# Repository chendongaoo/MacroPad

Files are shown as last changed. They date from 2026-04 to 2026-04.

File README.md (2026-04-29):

# MacroPad
A 6 key and 1 rotary encoder macropad designed so I can learn pcbs.

This was my first time ever doing a hardware project involving PCBs so I would say this was a really educational and fun experience!

# CAD Model
The case of the macropad was built through AutoDesk Inventor




# PCB
I used KiCAD for the pcb design and also the schematics.

- Schematic
- Schematic Picture
- PCB Design
- PCB Picture

# Firmware
QMK Firmware was used in order to make the firmware of the macropad. I was able to let it have my 6 keys type different letters out and also have the rotary encoder be for volume.

# BOM (Bill of Materials)
|Quantity|Item|Link|
|---|---|---|
|1|Seeed XIAO RP2040|https://www.seeedstudio.com/XIAO-RP2040-v1-0-p-5026.html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|
|1|EC11 Rotary Encoder|https://keeb.io/products/rotary-encoder-ec11?srsltid=AfmBOopjsudrm_2NT5rApQGzpvWgGaP1affFDQzp-gO6didcxRWisLA-|
|4|M3x16mm Screws|https://www.homedepot.com/p/Hillman-M3-0-5-x-16-mm-Internal-Hex-Button-Head-Cap-Screws-16-Pack-44458/204801177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|
|6|MX-Style Switches|https://www.gateron.co/collections/mx-switches/products/gateron-switch-set|
|6|White Blank DSA Keycaps|https://www.adafruit.com/product/4998?srsltid=AfmBOoqWXq0PUuXsWHtaNkMeOQ-MZJd006PQ38bVfjTifiNstVszIAVgm1U|
|PCB Estimated Price|$2.10|

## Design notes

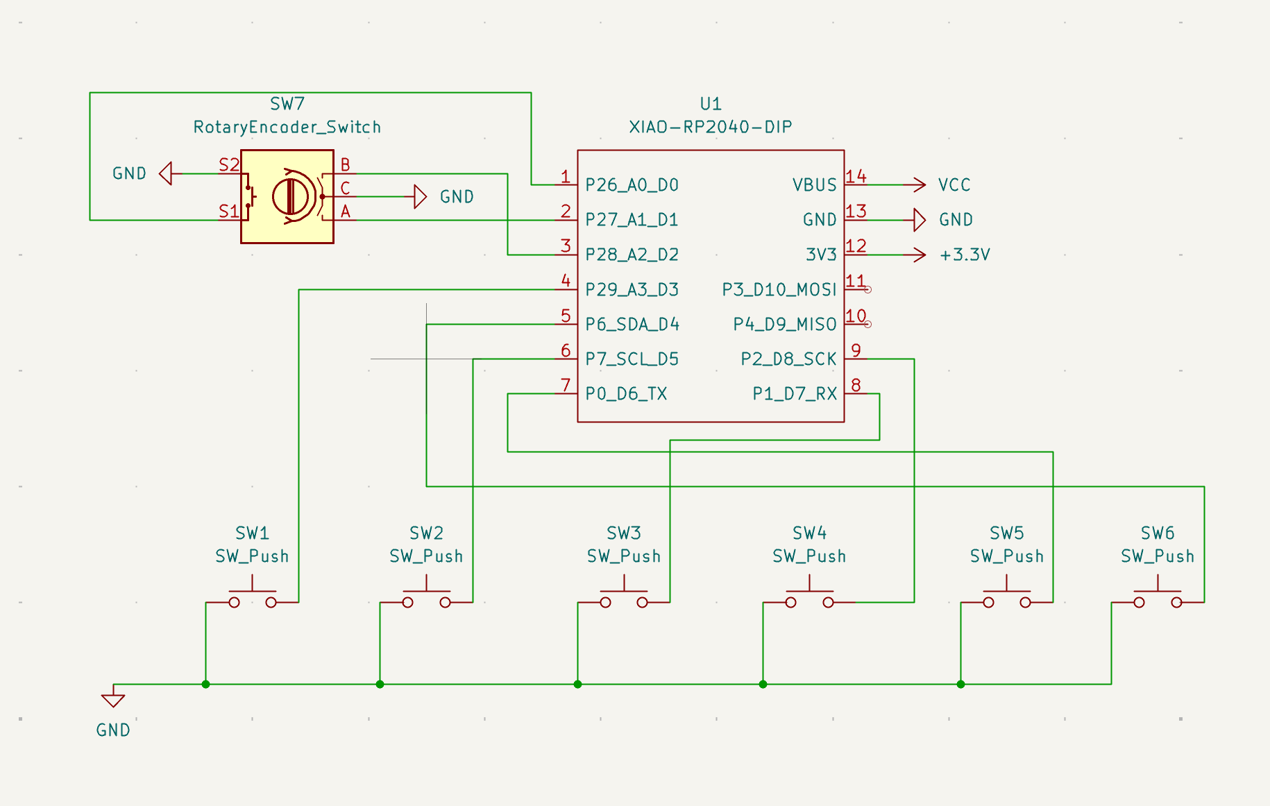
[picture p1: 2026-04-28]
PCB/Schematic Picture.png

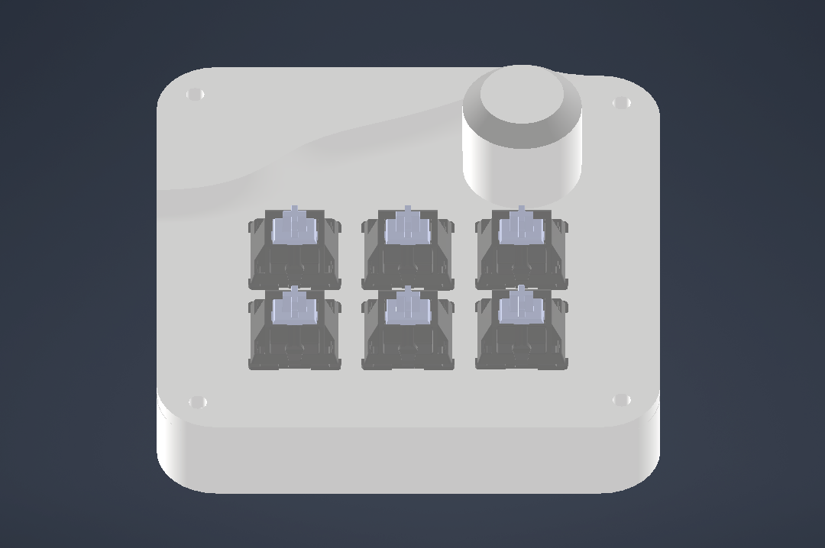
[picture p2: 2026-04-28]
CAD/Pic2.png

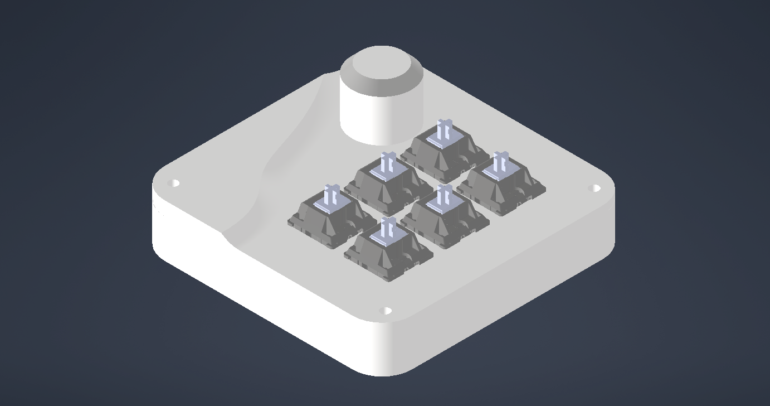
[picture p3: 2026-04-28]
CAD/Pic.png

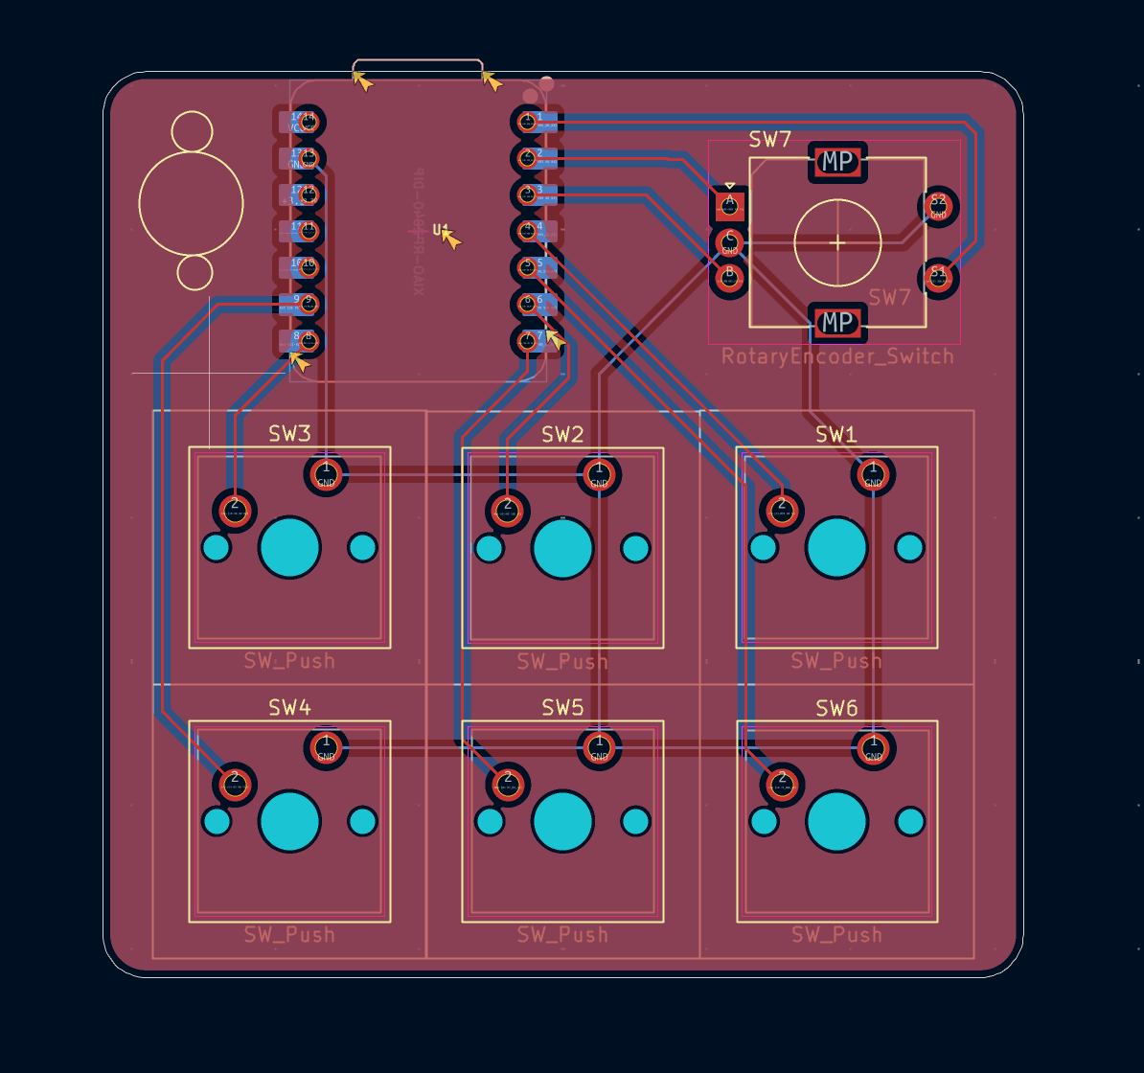
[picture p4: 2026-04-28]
PCB/PCB Picture.png

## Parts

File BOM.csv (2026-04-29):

Quantity | Item | Link
1 | Seeed XIAO RP2040 | https://www.seeedstudio.com/XIAO-RP2040-v1-0-p-5026.html
1 | EC11 Rotary Encoder | https://keeb.io/products/rotary-encoder-ec11
4 | M3x16mm Screws | https://www.homedepot.com/p/Hillman-M3-0-5-x-16-mm-Internal-Hex-Button-Head-Cap-Screws-16-Pack-44458/204801177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
6 | MX-Style Switches | https://www.gateron.co/collections/mx-switches/products/gateron-switch-set
6 | White Blank DSA Keycaps | https://www.adafruit.com/product/4998
PCB Estimated Price | $2.10

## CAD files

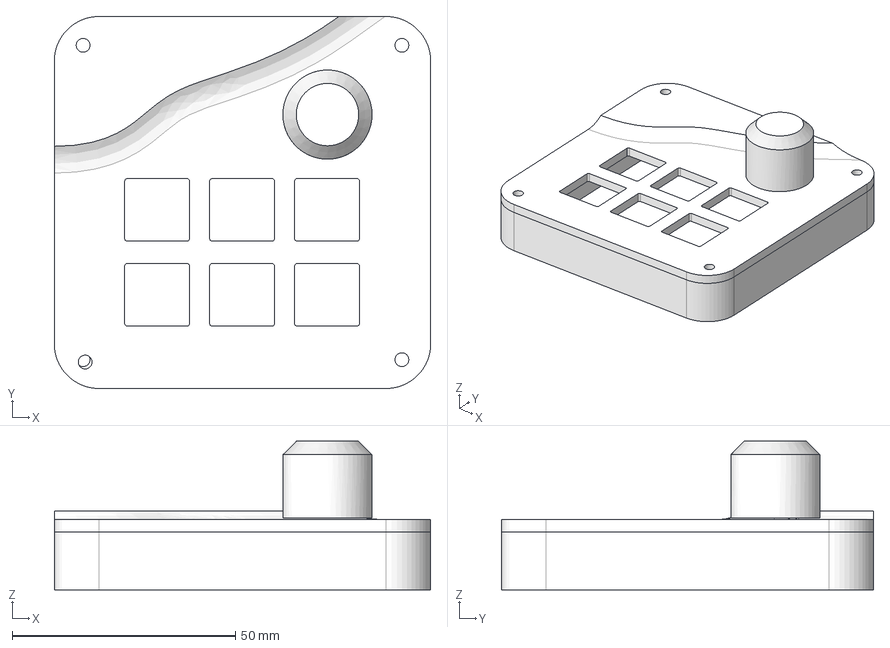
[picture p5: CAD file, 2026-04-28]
CAD/Assembly Files/MacroPadCase.stp
84.4 x 83.4 x 33.3 mm
Base
Cover
Knob

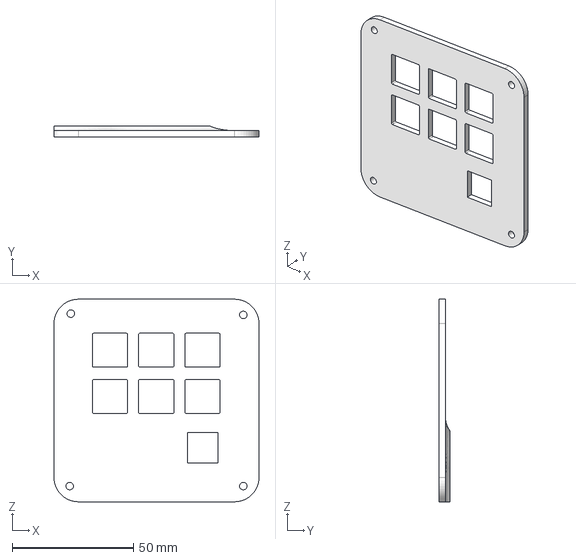
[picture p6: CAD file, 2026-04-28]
CAD/Part Files/Cover.stp
84.4 x 4.70 x 83.4 mm

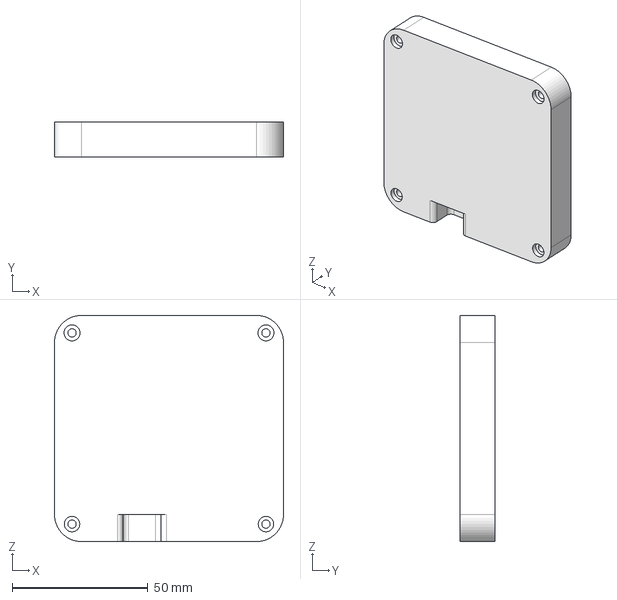
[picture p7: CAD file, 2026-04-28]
Production/Base.stp
84.4 x 13.0 x 83.4 mm

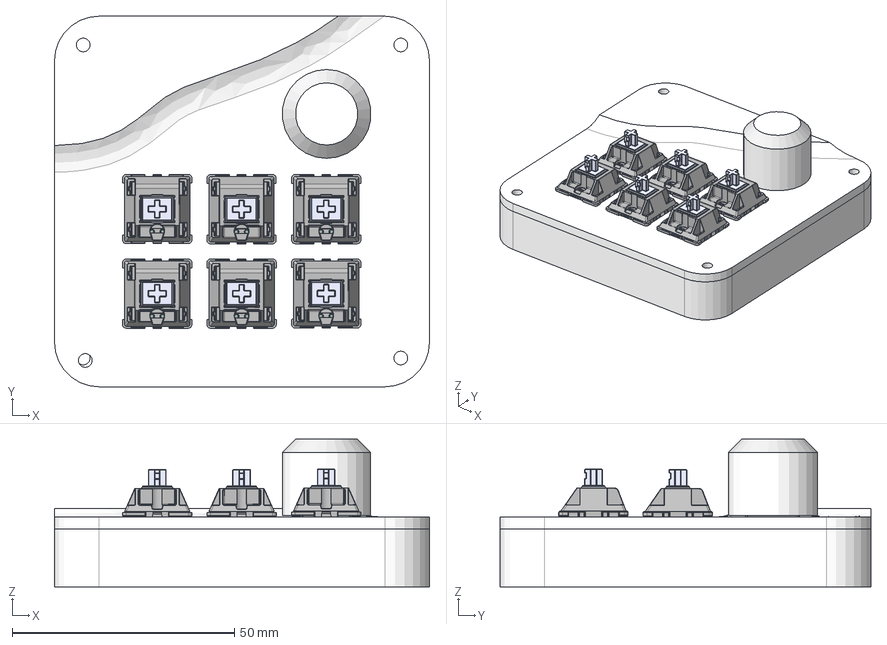
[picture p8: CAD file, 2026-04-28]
CAD/Assembly Files/MacroPadCase-PCB.stp
84.4 x 83.4 x 33.3 mm
���___Ĭ��__��_ x 6
MX�� ���� �ײ� �̡�2 __Ĭ��_��2____��_ x 6
MX �� ������_��_ __��1 x 6
MX �� ���娢��_���顧_ _ x 6
���___Ĭ��__��_ _1 x 6
Rotaryencoder
MacroPad_silkscreen
MacroPad_silkscreen_1
MacroPad_soldermask
MacroPad_soldermask_1
MacroPad_PCB
Base
Cover
Knob

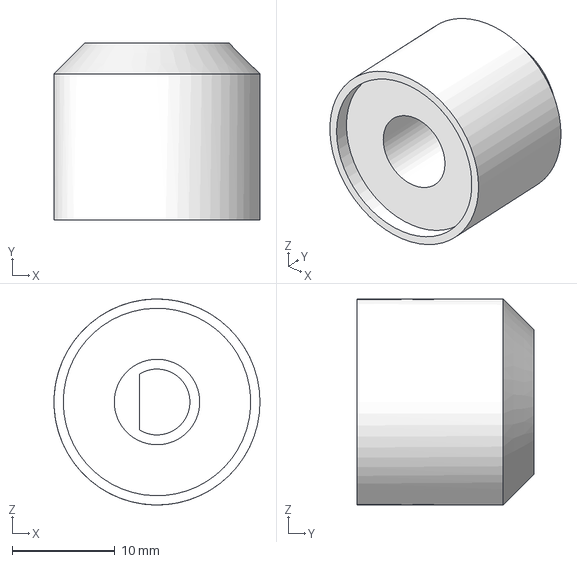
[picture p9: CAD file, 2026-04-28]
Production/Knob.stp
20.0 x 17.2 x 20.0 mm

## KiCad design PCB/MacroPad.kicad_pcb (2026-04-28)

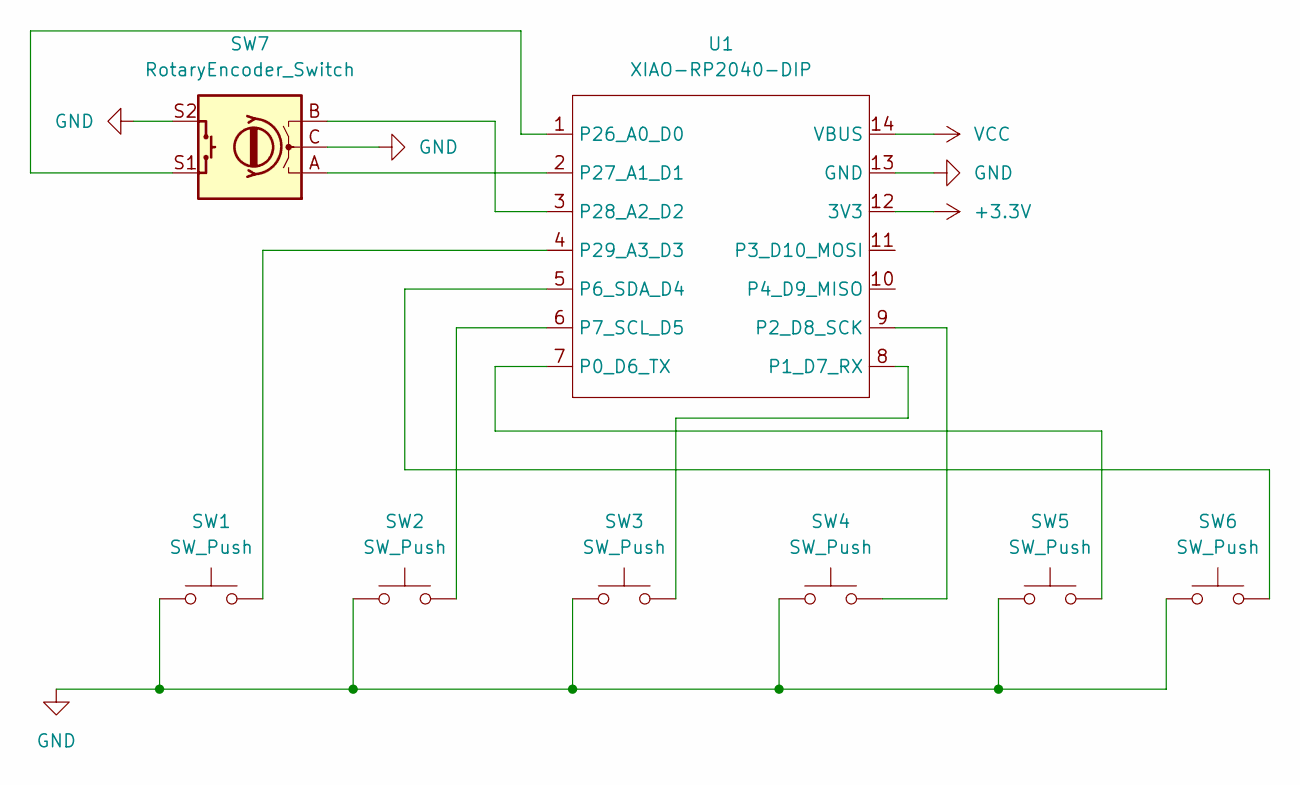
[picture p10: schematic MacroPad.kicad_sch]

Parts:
SW1, SW2, SW3, SW4, SW5, SW6: SW_Push; SW_Cherry_MX_1.00u_PCB
SW7: RotaryEncoder_Switch; RotaryEncoder_Alps_EC11E-Switch_Vertical_H20mm
U1: XIAO-RP2040-DIP

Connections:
+3.3V: U1.12 (3V3)
GND: SW1.1, SW2.1, SW3.1, SW4.1, SW5.1, SW6.1, SW7.C, SW7.S2, U1.13 (GND)
unnamed: SW5.2, U1.7 (P0_D6_TX)
unnamed: SW3.2, U1.8 (P1_D7_RX)
unnamed: SW4.2, U1.9 (P2_D8_SCK)
unnamed: SW6.2, U1.5 (P6_SDA_D4)
unnamed: SW2.2, U1.6 (P7_SCL_D5)
unnamed: SW7.S1, U1.1 (P26_A0_D0)
unnamed: SW7.A, U1.2 (P27_A1_D1)
unnamed: SW7.B, U1.3 (P28_A2_D2)
unnamed: SW1.2, U1.4 (P29_A3_D3)
VCC: U1.14 (VBUS)

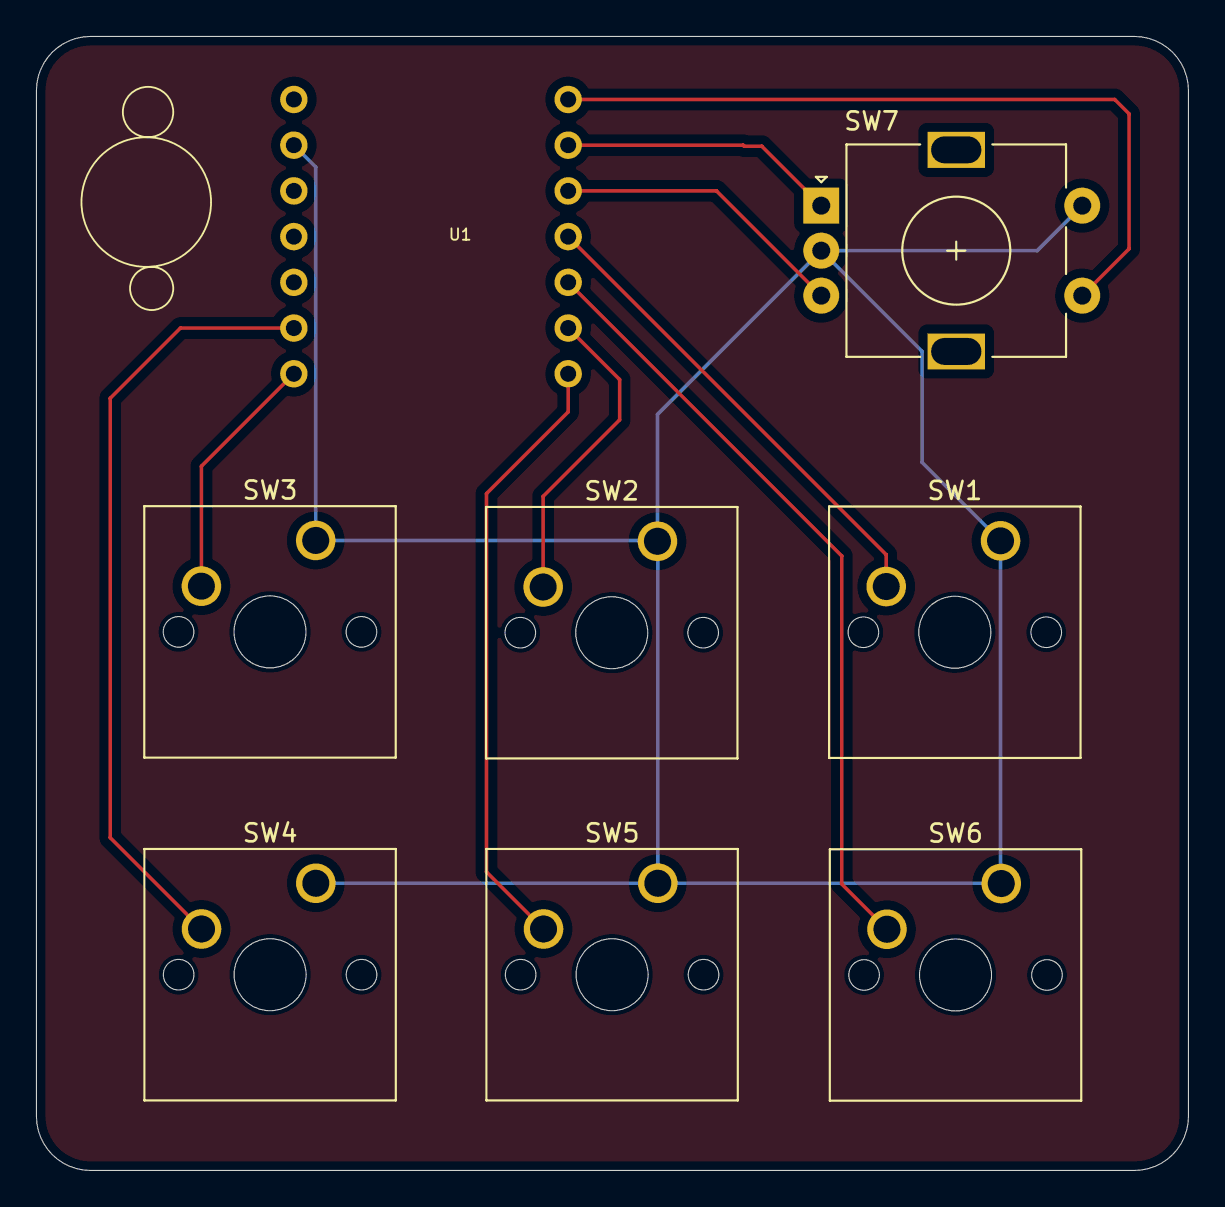
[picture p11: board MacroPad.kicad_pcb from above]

Board: 2 copper layers, 64.0 x 63.0 mm, 8 parts (1 on the bottom side), 10 nets.

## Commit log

2026-04-28 added files for project
    [Base.stp, Cover.stp, Knob.stp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]
2026-04-28 reorganizing files
    [Base.stp, Cover.stp, Knob.stp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]
2026-04-28 added BOM
    [BOM.csv]
